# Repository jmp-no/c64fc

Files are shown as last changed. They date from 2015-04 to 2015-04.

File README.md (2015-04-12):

# c64fc
All software related to the C64FC (Commodore 64 Flash Cart)

Firmware:

Holds the source code to build and flash the firmware.

USBaspLoader 

- USB boot loader for the AVR.

c64firmware 

- firmware sourcecode.

Hardware:

Contains Hardware schematics of the C64FC card in brd/sch format.	
	
Software:

Qt64 

- QT GUI frontend to handle upload/download of c64 images.

SIDPlay 

- QT GUI frontend to handle SID playing.

cmd64 

- Command tools to upload/download/reset/set bootloader.	
libc64fc -libc64fc library. Needed for all above as dep.

C64 images/sids needs to be placed under ROMs/C64Music.

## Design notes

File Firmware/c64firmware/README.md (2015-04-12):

C64FC firmware:

Requires:

- avrdude
- avr-gcc (i.e arduino-1.x.0/hardware/tools/avr/bin/avr-gcc)

To build:

make

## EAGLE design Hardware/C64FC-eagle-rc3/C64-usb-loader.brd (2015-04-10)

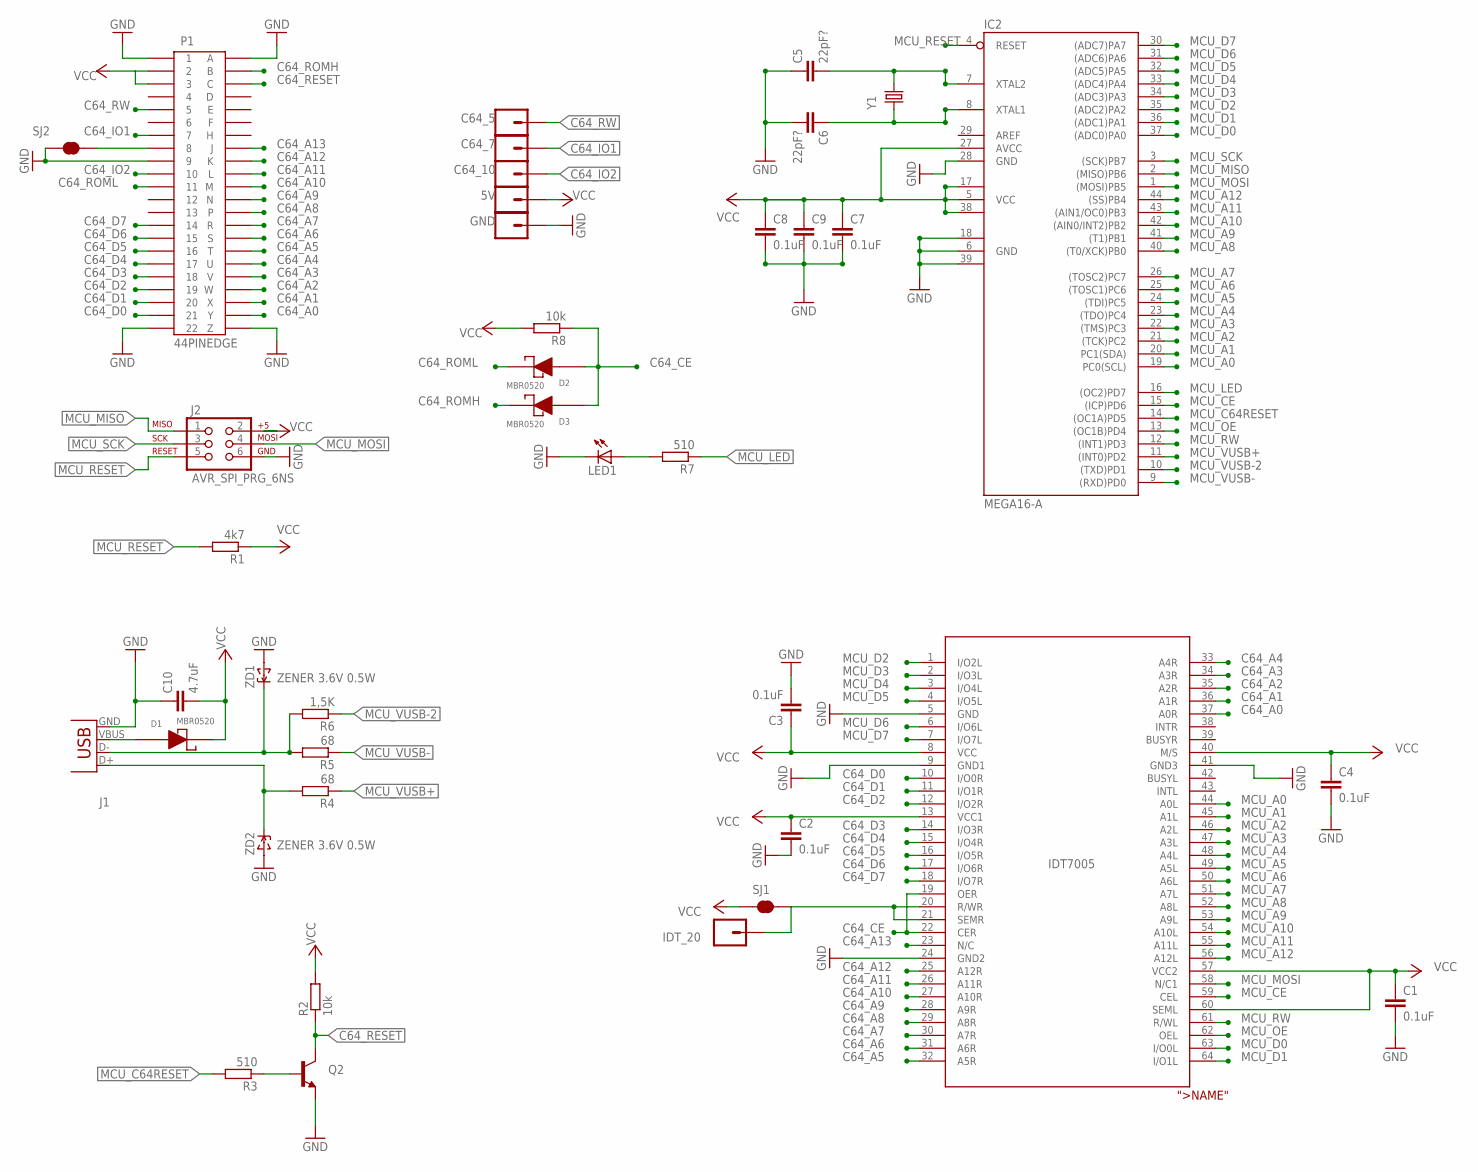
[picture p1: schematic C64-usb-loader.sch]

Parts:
5V: M01PTH; 1X01
C1, C2, C3, C4, C7, C8, C9: 0.1uF; C0805
C5, C6: 22pF?; C0805
C10: 4.7uF; C0805
C64_5, C64_7, C64_10: M01PTH; 1X01
D1, D2, D3: MBR0520; SOD-123; DIGIKEY MBR0520LCT-ND
GND: M01PTH; 1X01
IC1: IDT7005; TQFP64; DIGIKEY 800-1357-5-ND ??
IC2: MEGA16-A; TQFP44; DIGIKEY ATMEGA16A-AURCT-ND ??
IDT_20: M01PTH; 1X01
J1: USB-B; B; DIGIKEY ED2983-ND ??
J2: AVR_SPI_PRG_6NS; 2X3-NS
LED1: LED1206; LED-1206
P1: 44PINEDGE
Q2: TRANSISTOR_NPNSOT23-3; SOT23-3; DIGIKEY MMBT2222A-FDICT-ND
R1: 4k7; M0805
R2, R8: 10k; M0805
R3, R7: 510; M0805
R4, R5: 68; M0805
R6: 1,5K; M0805
SJ1, SJ2: JUMPER-PAD-2-NC_BY_TRACE; PAD-JUMPER-2-NC_BY_TRACE_YES_SILK
Y1: CRYSTALHC49US; HC49US
ZD1, ZD2: ZENER 3.6V 0.5W; SOD-123; DIGIKEY MMSZ5227B-FDICT-ND ??

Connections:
C64_A0: IC1.37 (A0R), P1.Y
C64_A1: IC1.36 (A1R), P1.X
C64_A2: IC1.35 (A2R), P1.W
C64_A3: IC1.34 (A3R), P1.V
C64_A4: IC1.33 (A4R), P1.U
C64_A5: IC1.32 (A5R), P1.T
C64_A6: IC1.31 (A6R), P1.S
C64_A7: IC1.30 (A7R), P1.R
C64_A8: IC1.29 (A8R), P1.P
C64_A9: IC1.28 (A9R), P1.N
C64_A10: IC1.27 (A10R), P1.M
C64_A11: IC1.26 (A11R), P1.L
C64_A12: IC1.25 (A12R), P1.K
C64_A13: IC1.23 (N/C), P1.J
C64_CE: D2.2 (AN), D3.2 (AN), IC1.19 (OER), IC1.22 (CER), R8.1
C64_D0: IC1.10 (I/O0R), P1.21
C64_D1: IC1.11 (I/O1R), P1.20
C64_D2: IC1.12 (I/O2R), P1.19
C64_D3: IC1.14 (I/O3R), P1.18
C64_D4: IC1.15 (I/O4R), P1.17
C64_D5: IC1.16 (I/O5R), P1.16
C64_D6: IC1.17 (I/O6R), P1.15
C64_D7: IC1.18 (I/O7R), P1.14
C64_GAME: P1.8, SJ2.2
C64_IO1: C64_7.1, P1.7
C64_IO2: C64_10.1, P1.10
C64_RESET: P1.C, Q2.3 (C), R2.1
C64_ROMH: D3.1 (CA), P1.B
C64_ROML: D2.1 (CA), P1.11
C64_RW: C64_5.1, P1.5
D+: J1.D+, R4.2, ZD2.C
D-: J1.D-, R5.2, R6.2, ZD1.C
GND: C1.2, C2.2, C3.2, C4.2, C5.1, C6.2, C7.2, C8.2, C9.2, C10.1, GND.1, IC1.5 (GND), IC1.9 (GND1), IC1.24 (GND2), IC1.41 (GND3), IC2.6 (GND), IC2.18 (GND1), IC2.28 (GND), IC2.39 (GND2), J1.GND, J2.6, LED1.C, P1.1, P1.9, P1.22, P1.A, P1.Z, Q2.2 (E), SJ2.1, ZD1.A, ZD2.A
MCU_A0: IC1.44 (A0L), IC2.19 (PC0(SCL))
MCU_A1: IC1.45 (A1L), IC2.20 (PC1(SDA))
MCU_A2: IC1.46 (A2L), IC2.21 ((TCK)PC2)
MCU_A3: IC1.47 (A3L), IC2.22 ((TMS)PC3)
MCU_A4: IC1.48 (A4L), IC2.23 ((TDO)PC4)
MCU_A5: IC1.49 (A5L), IC2.24 ((TDI)PC5)
MCU_A6: IC1.50 (A6L), IC2.25 ((TOSC1)PC6)
MCU_A7: IC1.51 (A7L), IC2.26 ((TOSC2)PC7)
MCU_A8: IC1.52 (A8L), IC2.40 ((T0/XCK)PB0)
MCU_A9: IC1.53 (A9L), IC2.41 ((T1)PB1)
MCU_A10: IC1.54 (A10L), IC2.42 ((AIN0/INT2)PB2)
MCU_A11: IC1.55 (A11L), IC2.43 ((AIN1/OC0)PB3)
MCU_A12: IC1.56 (A12L), IC2.44 ((SS)PB4)
MCU_C64RESET: IC2.14 ((OC1A)PD5), R3.2
MCU_CE: IC1.59 (CEL), IC2.15 ((ICP)PD6)
MCU_D0: IC1.63 (I/O0L), IC2.37 ((ADC0)PA0)
MCU_D1: IC1.64 (I/O1L), IC2.36 ((ADC1)PA1)
MCU_D2: IC1.1 (I/O2L), IC2.35 ((ADC2)PA2)
MCU_D3: IC1.2 (I/O3L), IC2.34 ((ADC3)PA3)
MCU_D4: IC1.3 (I/O4L), IC2.33 ((ADC4)PA4)
MCU_D5: IC1.4 (I/O5L), IC2.32 ((ADC5)PA5)
MCU_D6: IC1.6 (I/O6L), IC2.31 ((ADC6)PA6)
MCU_D7: IC1.7 (I/O7L), IC2.30 ((ADC7)PA7)
MCU_LED: IC2.16 ((OC2)PD7), R7.1
MCU_MISO: IC2.2 ((MISO)PB6), J2.1
MCU_MOSI: IC1.58 (N/C1), IC2.1 ((MOSI)PB5), J2.4
MCU_OE: IC1.62 (OEL), IC2.13 ((OC1B)PD4)
MCU_RESET: IC2.4 (RESET), J2.5, R1.2
MCU_RW: IC1.61 (R/WL), IC2.12 ((INT1)PD3)
MCU_SCK: IC2.3 ((SCK)PB7), J2.3
MCU_VUSB+: IC2.11 ((INT0)PD2), R4.1
MCU_VUSB-: IC2.9 ((RXD)PD0), R5.1
MCU_VUSB-2: IC2.10 ((TXD)PD1), R6.1
unnamed: Q2.1 (B), R3.1
unnamed: C5.2, IC2.7 (XTAL2), Y1.2
unnamed: IC1.20 (R/WR), IC1.21 (SEMR), IDT_20.1, SJ1.2
unnamed: C6.1, IC2.8 (XTAL1), Y1.1
unnamed: LED1.A, R7.2
VBUS: D1.2 (AN), J1.VBUS
VCC: 5V.1, C1.1, C2.1, C3.1, C4.1, C7.1, C8.1, C9.1, C10.2, D1.1 (CA), IC1.8 (VCC), IC1.13 (VCC1), IC1.40 (M/S), IC1.57 (VCC2), IC1.60 (SEML), IC2.5 (VCC), IC2.17 (VCC1), IC2.27 (AVCC), IC2.38 (VCC2), J2.2, P1.2, P1.3, R1.1, R2.2, R8.2, SJ1.1

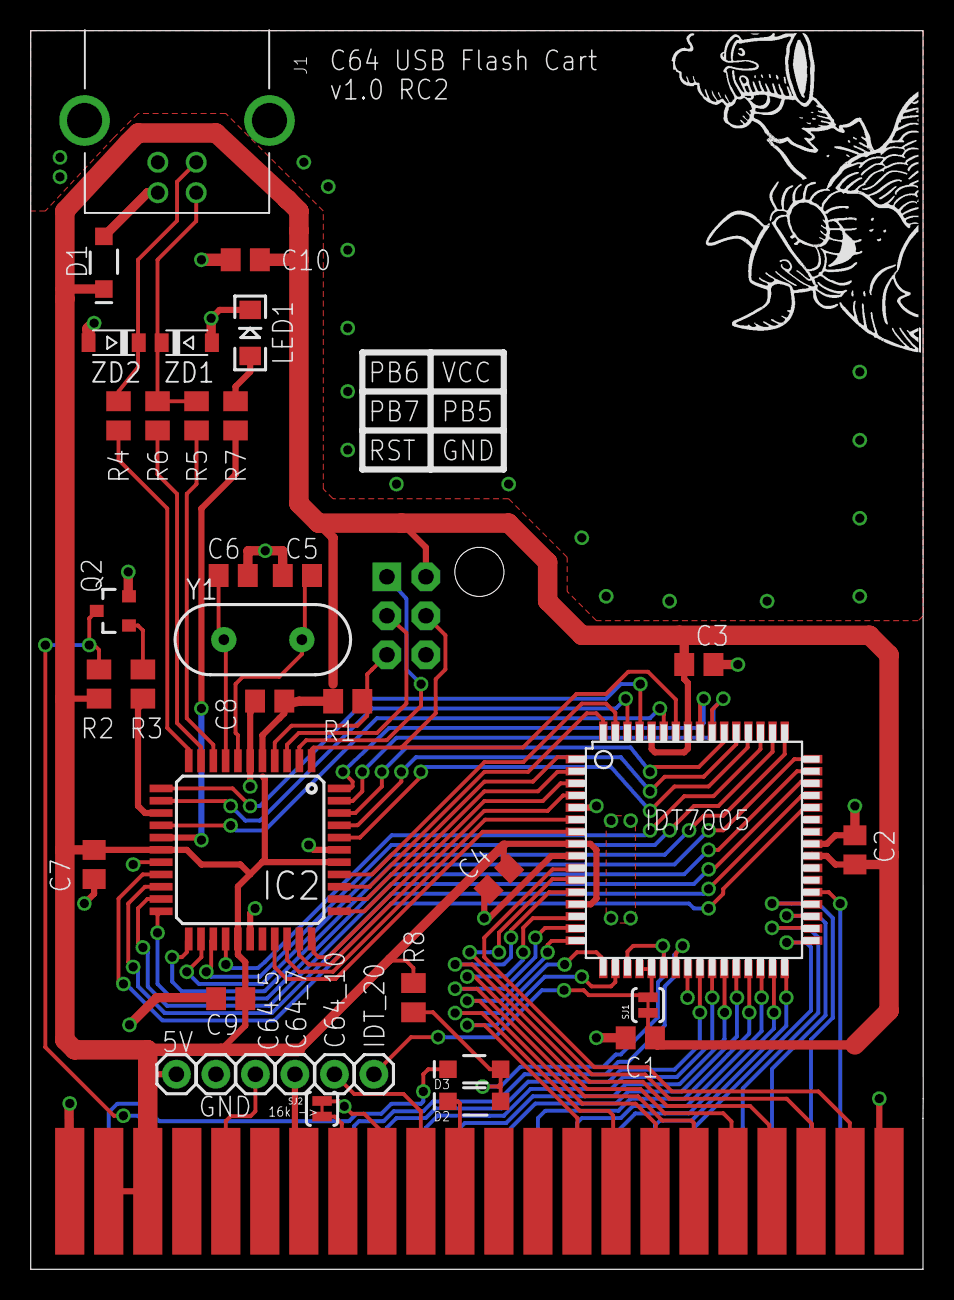
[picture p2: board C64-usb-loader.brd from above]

Board: 2 copper layers, 58.1 x 80.6 mm, 40 parts (0 on the bottom side), 73 nets.

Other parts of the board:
U$1: HAREK_20X16MM

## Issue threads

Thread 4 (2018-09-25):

the usbdrv used

bwack, 2018-09-25:
Hei. Lenge siden ! Alt over lenge siden.
Håper det er greit å spørre her ? Jeg har sett litt på firmware.

Jeg har "gått i stå" med videopac sdkort leser koden. Problemet er at menuprogrammet må ligge i rom når programmet overføres til ram via sd-cort -> videopac -> ram (fordi videopac styrer addressebussen selv, og for å slippe å bruke bustranscievers). Nå har jeg innsett at jeg trenger endel gluelogic + en rom brikke. Alikevel har jeg lyst å se om det går. Det er vanskelig å utvikle ved å brenne en rom hver gang, så kom jeg til å tenke på c64fc og dual port ram. Har veldig lyst å droppe hele designet og gå for arduino+ram+transcievers. Fordelen er jo også at man kan ha menuprogrammet på sdkort.. Kanskje starte med et kort som også har dualport ram slik at det blir lettere å utvikle (compile -> usb -> ram)..

Er det vanskelig å bruke usbdrv.h ? Jeg ser på koden og ser egentlig ganske greit ut :) Iallefal på mcu-siden. Ser ut som man trenger å definere noen funksjoner og en hid descriptor.

bwack, 2018-09-26:
Hadde det vært ok om jeg bruker ditt design for å lage et "break-out" kort med dpram, atmega og arduino ? Vi snakket en gang om å lage en standard for mange forskjellige cartridges. Akkurat nå tenker jeg på å bare lage en usb->rom utviklingskort :)

skurk, 2018-09-27:
Heisann, beklager sent svar.

V-USB er lett å bruke ja. Jeg betalte vel 10 euro for å få en unik ID. Du bruker hva du vil i utviklingsprosessen/testing, men for et "ferdig produkt" så kan det vel lønne seg å ha noe ryddig på plass.

Ikke noe problem å basere designet ditt på det jeg har heller. Er jo så og si klart, det du i all hovedsak trenger er en annen connector på enden, så er det tut og kjør. Ingenting C64-spesifikt med cartrigden annet enn connectoren...

bwack, 2018-10-01:
Takk! Har tegnet ett kort i KiCad basert på ditt kort. PCB designet er smellt sammen med autorouter bare for å ha noe å utvikle. Har bestilt komponenter og pcb. Håper på ha det klart i slutten av uka, begynnelsen av neste. :)

skurk, 2018-10-02:
Tøft! :-) Hold meg oppdatert med framgangen :)

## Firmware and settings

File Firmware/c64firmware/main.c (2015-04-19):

#include <avr/io.h>
#include <avr/interrupt.h>
#include <avr/pgmspace.h>
#include <avr/wdt.h>
#include <util/delay.h>

#include "usbdrv.h"

#include "c64.h"
#include "dpram.h"
#include "bootloader.h"
#include <string.h>    // Used for memcpy

#define C64FC_16K		0x16
#define C64FC_8K		0x08
#define C64FC_SETMODE   0x04

#define C64FC_GETSIZE   0x20

#define C64FC_RESET		0xf0
#define C64FC_WRITEDATA	0xcc
#define C64FC_READDATA	0xcd
#define C64FC_SETADDR	0x64

#define C64FC_BOOTLOADER 0xFE
#define C64FC_APIVERSION 0xF1


/* API Version
 * This is used to check that the cart and pc software is "talking the same language"
 * Increment this every time there is a change in the usb communication statck
*/
#define API_VERSION_HIGH 0x00;
#define API_VERSION_LOW  0x01;

#define LED_ON	PORTD |=  (1 << 7)
#define LED_OFF PORTD &= ~(1 << 7)
/*#define LED_ON	PORTD |= 0b10000000
#define LED_OFF PORTD &= 0b01111111*/

typedef struct __attribute__((packed)){
   uint16_t address;
   char len;
   char data[128];  
} dataBlock;

uint16_t address = 0;

uint8_t dataINFunction  = 0;
uint8_t dataOUTFunction = 0;
/* ------------------------------------------------------------------------- */
/* ----------------------------- USB interface ----------------------------- */
/* ------------------------------------------------------------------------- */

PROGMEM const char usbHidReportDescriptor[22] = {    /* USB report descriptor */
    0x06, 0x00, 0xff,              // USAGE_PAGE (Generic Desktop)
    0x09, 0x01,                    // USAGE (Vendor Usage 1)
    0xa1, 0x01,                    // COLLECTION (Application)
    0x15, 0x00,                    //   LOGICAL_MINIMUM (0)
    0x26, 0xff, 0x00,              //   LOGICAL_MAXIMUM (255)
    0x75, 0x08,                    //   REPORT_SIZE (8) 0x08
    0x95, 0x80,                    //   REPORT_COUNT (128)
    0x09, 0x00,                    //   USAGE (Undefined)
    0xb2, 0x02, 0x01,              //   FEATURE (Data,Var,Abs,Buf)
    0xc0                           // END_COLLECTION
};
/* Since we define only one feature report, we don't use report-IDs (which
 * would be the first byte of the report). The entire report consists of 128
 * opaque data bytes.
 */

/* The following va1iables store the status of the current data transfer */
static uchar    bytesRemaining;
//static uint8_t enter_bootloader = 0;

/* ------------------------------------------------------------------------- */

/* usbFunctionRead() is called when the host requests a chunk of data from
 * the device. For more information see the documentation in usbdrv/usbdrv.h.
 */
uchar   usbFunctionRead(uchar *data, uchar len)
{
    if(len > bytesRemaining)
        len = bytesRemaining;
    bytesRemaining -= len;

    return len;
}

/* usbFunctionWrite() is called when the host sends a chunk of data to the
 * device. For more information see the documentation in usbdrv/usbdrv.h.
 */


/* Jeg må bare innse at denne ikke kjøres for hver "packet", men deles opp utenfor min kontroll. */

uchar   usbFunctionWrite(uchar *data, uchar len)
{
	uint8_t i=0;
	LED_ON;

	if(bytesRemaining == 0)
		return 1;               // end of transfer 

	if(len > bytesRemaining)
		len = bytesRemaining;

	switch( dataINFunction ) {
		case 1:
			for( i = 0; i<len; i++ )
				DPRAM_write( address+i, (unsigned char) data[i] );
			address += len;
			break;
		case 2:
			address = ((unsigned char)data[0] << 8)|(unsigned char)data[1];
			break;
		case 3: 
		    /* MODE CHANGE */
			if      (data[0] == 0x00) C64_NOCART();
			else if (data[0] == 0x01) C64_8K();
			else if (data[0] == 0x02) C64_16K();
			else if (data[0] == 0x03) C64_ULTIMAX();

		    break;
		default:
			break;
	}

	bytesRemaining -= len;
	LED_OFF;
	return bytesRemaining == 0; // return 1 if this was the last chunk 
}

/* ------------------------------------------------------------------------- */

usbMsgLen_t usbFunctionSetup(uchar data[8])
{
	usbRequest_t    *rq = (void *)data;

	uint8_t retval = USB_NO_MSG;

	LED_ON;

	if((rq->bmRequestType & USBRQ_TYPE_MASK) == USBRQ_TYPE_CLASS) {
		if(rq->bRequest == USBRQ_HID_SET_REPORT){
			uint8_t command = rq->wValue.bytes[0];
			switch( command ) {
				case C64FC_8K:
					/* 0x08 8k mode
					 * Makes the C64FC enter 8k mode 
					 * Then reboots the C64 to load data from C64FC
					 */
					C64_EXROM(0);
					C64_GAME(1);
					C64_Reset();
					LED_OFF;
					retval = 1;
					bytesRemaining = 0;
					break;
				case C64FC_16K:
					/* 0x16 16k mode
					 * Makes the C64FC enter 16k mode 
					 * Then reboots the C64 to load data from C64FC
					 */
					C64_EXROM(0);
					C64_GAME(0);
					C64_Reset();
					LED_OFF;
					retval = 1;
					bytesRemaining = 0;
					break;
				case C64FC_SETMODE:
					/* Changes mode on the cart
					 * Same function for all modes
					 * uses parameter from PC, values: 
					 * 0: diabled , 1: 8k,    2: 16k , 3: ultimax
					 */
					bytesRemaining = rq->wLength.bytes[0];
					dataINFunction = 3;
					break;
				case C64FC_WRITEDATA:
					/* 0xCC Send Data
					 * Data sent from pc to the C64FC
					 * Uses usbFunctionWrite to save recieved data to RAM
					 * Saves data to address set with C64FC_SETADDR
					 */
					bytesRemaining = rq->wLength.bytes[0];
					dataINFunction = 1;
					break;
				case C64FC_SETADDR:
					/* 0x64 Set Address
					 * Sets the address for the next read/write operation
					 * Uses usbFunctionWrite to get the address
					 */
					//bytesRemaining = rq->wLength.bytes[0];  // This did'nt work.. :( dont know if its because of S64FC or client software...)
					dataINFunction = 2;
					bytesRemaining = 2;

					break;
				case C64FC_RESET:
					/* 0xF0 Reset C64
					 * Resets the C64 
					 */
					//address = 0;
					C64_Reset();
					LED_OFF;
					retval = 1;
					bytesRemaining = 0;
					break;
				case C64FC_BOOTLOADER:
					/* 0xFE Enter Bootloader
					 * Puts the C64FC in bootloader mode.
					 * C64FC will be stuck in UsbASPloader until MCUCSR != 0 or avrdude sends a exit command.
					 * 
					 */
					 wdt_disable();
					MCUCSR = 0;
					bootloader_jump();		// This needs to be moved... bootloader_jump is creating a "Broken pipe on the host.."
										// Create a var and check for it in main:for(;;)  then execute bootloader_jump() before the next usb_poll.
					//enter_bootloader = 1;
					
					break;
			}
		} else if(rq->bRequest == USBRQ_HID_GET_REPORT){
			uint8_t command = rq->wValue.bytes[0];
			//uint8_t index0 = rq->wIndex.bytes[0];
			//uint8_t index1 = rq->wIndex.bytes[1];
			static uchar smallReturnBuffer[10];
			static uchar largeReturnBuffer[128];

			switch ( command ) {			
				case 0x01: ;
					/* 0x01 Return fubar to PC
					 * only for testing.. :)
					 *  --runar
					 */
					LED_OFF;
					retval = 6;
					static uchar pointer[5] = "fiske";
					usbMsgPtr = pointer;
					DPRAM_write(0x00, (uint8_t)'f');
					DPRAM_write(0x01, (uint8_t)'u');
					DPRAM_write(0x02, (uint8_t)'b');
					DPRAM_write(0x03, (uint8_t)'a');
					DPRAM_write(0x04, (uint8_t)'r');
					pointer[0] = DPRAM_read(0x00);
					pointer[1] = DPRAM_read(0x01);
					pointer[2] = DPRAM_read(0x02);
					pointer[3] = DPRAM_read(0x03);
					pointer[4] = DPRAM_read(0x04);
					pointer[4] = rq->wLength.bytes[0];
					LED_OFF;
					break;
				case C64FC_GETSIZE:	;
					/* 0x20 Get size of DPRAM
					 * Calculates the size of your DPRAM chip.
					 * supports 8k and 16k.
					 * Writes to 0x0 and compares with value at 0x2000.
					 * Se DPRAM_size in dpram.c for more info
					 */
					if (DPRAM_size() == 0x2000)
						smallReturnBuffer[0] =  8;
					else
						smallReturnBuffer[0] = 16;
					retval=10;				// Retval on GET request is number of bytes returned
					usbMsgPtr = smallReturnBuffer;
					LED_OFF;
					break;
				case C64FC_READDATA: ;
					/* 0xCD Read data from device
					 * Reads data from address set by C64FC_SETADDR
					 * 
					 */
					uint8_t i;
					for( i = 0; i<rq->wLength.bytes[0]; i++ ) {
						largeReturnBuffer[i] = DPRAM_read( address+i );
					}
					address  += rq->wLength.bytes[0];	// Address is incremented for next read...
					retval    = rq->wLength.bytes[0];	// Retval on GET request is number of bytes returned
					usbMsgPtr = largeReturnBuffer;
					LED_OFF;
					break;
				case C64FC_APIVERSION: ;
					/* 0xF1 API Version
					 * This is used to check that the cart and pc software is "talking the same language"
					 * API_VERSION_HIGH/LOW is incremented every time there is a change in the usb protocoll stack.
					 */
					smallReturnBuffer[0] = API_VERSION_HIGH;
					smallReturnBuffer[1] = API_VERSION_LOW;
					retval=2;				// Retval on GET request is number of bytes returned
					usbMsgPtr = smallReturnBuffer;
					LED_OFF;
					break;
			}

		}
	}
	return( retval );
}

/* ------------------------------------------------------------------------- */

int main(void) {
uchar   i;

	C64_init();
	DPRAM_init();
	DPRAM_clear(0x0,0x4000);

	wdt_enable(WDTO_1S);
	usbInit();
	usbDeviceDisconnect();

	DDRD |= (1 << 7);    // LED init
//	DDRD |= (0b10000000);    // LED init
	LED_ON;
	i = 0;
	while(--i){
		wdt_reset();
		_delay_ms(1);
	}
	LED_OFF;

	usbDeviceConnect();
	sei();

	DPRAM_init();

// 8k mode
	C64_EXROM(1);
	C64_GAME(1);
	C64_Reset();

	for(;;) {                /* main event loop */
		wdt_reset();
		usbPoll();

/*		if (enter_bootloader > 0)
			enter_bootloader++;
			if (enter_bootloader <= 1000) {
				wdt_disable();
				MCUCSR = 0;
				bootloader_jump();		// This needs to be moved... bootloader_jump is creating a "Broken pipe on the host.."
										// Create a var and check for it in main:for(;;)  then execute bootloader_jump() before the next usb_poll.
			}*/
	}
	return 0;
}

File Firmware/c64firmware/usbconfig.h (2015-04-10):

/* Name: usbconfig.h
 * Project: AVR USB driver
 * Author: Christian Starkjohann
 * Creation Date: 2005-04-01
 * Tabsize: 4
 * Copyright: (c) 2005 by OBJECTIVE DEVELOPMENT Software GmbH
 * License: GNU GPL v2 (see License.txt) or proprietary (CommercialLicense.txt)
 * This Revision: $Id: usbconfig.h 43 2005-04-10 21:04:36Z cs $
 */

#ifndef __usbconfig_h_included__
#define __usbconfig_h_included__

/*
General Description:
This file contains parts of the USB driver which can be configured and can or
must be adapted to your hardware.

Please note that the usbdrv contains a usbconfig-prototype.h file now. We
recommend that you use that file as a template because it will always list
the newest features and options.
*/

/* ---------------------------- Hardware Config ---------------------------- */

#define USB_CFG_CLOCK_KHZ       (F_CPU/1000)

#define USB_CFG_IOPORTNAME      D
/* This is the port where the USB bus is connected. When you configure it to
 * "B", the registers PORTB, PINB and DDRB will be used.
 */
#define USB_CFG_DMINUS_BIT      0
/* This is the bit number in USB_CFG_IOPORT where the USB D- line is connected.
 * This may be any bit in the port.
 */
#define USB_CFG_DPLUS_BIT       2
/* This is the bit number in USB_CFG_IOPORT where the USB D+ line is connected.
 * This may be any bit in the port. Please note that D+ must also be connected
 * to interrupt pin INT0!
 */
/* #define USB_CFG_CLOCK_KHZ       (F_CPU/1000) */
/* Clock rate of the AVR in MHz. Legal values are 12000, 16000 or 16500.
 * The 16.5 MHz version of the code requires no crystal, it tolerates +/- 1%
 * deviation from the nominal frequency. All other rates require a precision
 * of 2000 ppm and thus a crystal!
 * Default if not specified: 12 MHz
 */

/* ----------------------- Optional Hardware Config ------------------------ */

#define USB_CFG_PULLUP_IOPORTNAME   D 
/* If you connect the 1.5k pullup resistor from D- to a port pin instead of
 * V+, you can connect and disconnect the device from firmware by calling
 * the macros usbDeviceConnect() and usbDeviceDisconnect() (see usbdrv.h).
 * This constant defines the port on which the pullup resistor is connected.
 */
 #define USB_CFG_PULLUP_BIT          1
/* This constant defines the bit number in USB_CFG_PULLUP_IOPORT (defined
 * above) where the 1.5k pullup resistor is connected. See description
 * above for details.
 */

/* --------------------------- Functional Range ---------------------------- */

#define USB_CFG_HAVE_INTRIN_ENDPOINT    1
/* Define this to 1 if you want to compile a version with two endpoints: The
 * default control endpoint 0 and an interrupt-in endpoint 1.
 */
#define USB_CFG_HAVE_INTRIN_ENDPOINT3   0
/* Define this to 1 if you want to compile a version with three endpoints: The
 * default control endpoint 0, an interrupt-in endpoint 1 and an interrupt-in
 * endpoint 3. You must also enable endpoint 1 above.
 */
#define USB_CFG_IMPLEMENT_HALT          0
/* Define this to 1 if you also want to implement the ENDPOINT_HALT feature
 * for endpoint 1 (interrupt endpoint). Although you may not need this feature,
 * it is required by the standard. We have made it a config option because it
 * bloats the code considerably.
 */
#define USB_CFG_INTR_POLL_INTERVAL      10
/* If you compile a version with endpoint 1 (interrupt-in), this is the poll
 * interval. The value is in milliseconds and must not be less than 10 ms for
 * low speed devices.
 */
#define USB_CFG_IS_SELF_POWERED         1
/* Define this to 1 if the device has its own power supply. Set it to 0 if the
 * device is powered from the USB bus.
 */
#define USB_CFG_MAX_BUS_POWER           20
/* Set this variable to the maximum USB bus power consumption of your device.
 * The value is in milliamperes. [It will be divided by two since USB
 * communicates power requirements in units of 2 mA.]
 */
#define USB_CFG_IMPLEMENT_FN_WRITE      1
/* Set this to 1 if you want usbFunctionWrite() to be called for control-out
 * transfers. Set it to 0 if you don't need it and want to save a couple of
 * bytes.
 */
#define USB_CFG_IMPLEMENT_FN_READ       1
/* Set this to 1 if you need to send control replies which are generated
 * "on the fly" when usbFunctionRead() is called. If you only want to send
 * data from a static buffer, set it to 0 and return the data from
 * usbFunctionSetup(). This saves a couple of bytes.
 */
#define USB_CFG_IMPLEMENT_FN_WRITEOUT   0
/* Define this to 1 if you want to use interrupt-out (or bulk out) endpoint 1.
 * You must implement the function usbFunctionWriteOut() which receives all
 * interrupt/bulk data sent to endpoint 1.
 */
#define USB_CFG_HAVE_FLOWCONTROL        0
/* Define this to 1 if you want flowcontrol over USB data. See the definition
 * of the macros usbDisableAllRequests() and usbEnableAllRequests() in
 * usbdrv.h.
 */
/* #define USB_RX_USER_HOOK(data, len)     if(usbRxToken == (uchar)USBPID_SETUP) blinkLED(); */
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

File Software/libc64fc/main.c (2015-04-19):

#include <stdio.h>
#include <string.h>
#include <unistd.h>
#include <math.h>
#include <usb.h>
#include "hiddata.h"
#include "../usbconfig.h"
#include "c64fc.h"


usbDevice_t *dev = NULL;
unsigned char buffer[129];

int OpenDevice() {
	unsigned char vendor_id[2] = { USB_CFG_VENDOR_ID };
	unsigned char product_id[2] = { USB_CFG_DEVICE_ID };
	char vendorName[] = { USB_CFG_VENDOR_NAME, 0 };
	char productName[] = { USB_CFG_DEVICE_NAME, 0 };
	int vid = vendor_id[0] + 256*vendor_id[1];
	int pid = product_id[0] + 256*product_id[1];
	int status;
	status = usbhidOpenDevice( &dev, vid, "jmp.no", pid, "C64FC-16", 0 );
	if (status == 0) return status;
	status = usbhidOpenDevice( &dev, vid, "jmp.no", pid, "C64FC-08", 0 );
	if (status == 0) return status;
	status = usbhidOpenDevice( &dev, vid, "jmp.no", pid, "C64FC", 0 );
	return( status );
}

void CloseDevice() {
	if( dev ) usbhidCloseDevice( dev );
	dev = NULL;
}

int Reset() {
	memset( buffer, 0, sizeof( buffer ));
	buffer[0] = C64FC_RESET;
	return( usbhidSetReport( dev, (char *) buffer, 1 ));
}

void SetAddress( unsigned short addr ) {
	int err=0;
	buffer[0] = C64FC_SETADDR;
	buffer[1] = (addr>>8)&0xff;
	buffer[2] = (addr&0xff);
	err = usbhidSetReport( dev, (char *) buffer, 129);
//	printf( "SetAddr=$%04x sent, response=%d\n", addr, err );
}


void Set8KMode() {
	int err = 0;
	buffer[0] = C64FC_8K;
	err = usbhidSetReport( dev, (char *) buffer, 1);
	printf( "SetCartMode=%d, res=%d", 8, err );
	Reset();
}

void Set16KMode() {
	int err = 0;
	buffer[0] = C64FC_16K;
	err = usbhidSetReport( dev, (char *) buffer, 1);
	printf( "SetCartMode=%d, res=%d", 16, err );
	Reset();
}

void SetMode(uint8_t mode) {
	/* Sets the GAME / EXROM pins on the C64
	 * Change is done without rebooting C64
	 * Parameter is the enum C64_MODE
	 */
	int err = 0;
	buffer[0] = C64FC_SETMODE;
	buffer[1] = mode;
	err = usbhidSetReport( dev, (char *) buffer, 1);
	printf( "SetCartMode=%d, res=%d", mode, err );
	Reset();
}
// Forslag til rewrite av WriteData...    
int WriteData( unsigned short address, unsigned char *data, int size ) {
	int err = 0;
	int chunk_no=0;
	int offset=0;

	if( !dev ) OpenDevice();
	SetAddress( address );

	while( size > 0 ) {

		int chunk_size = (size>=128)?128:size;
		memcpy( buffer+1, data+offset, chunk_size );
		buffer[0] = C64FC_DATA;
		printf( "Sending chunk %d (%d bytes) to $%04x..\n", chunk_no, chunk_size, address );
		//err = usbhidSetReport( dev, (char *) buffer, 129);
		err = usbhidSetReport( dev, (char *) buffer, chunk_size+1);  // <-- len is set to chunk_size+1.. wee need to remember the first reportid char... 
//		printf( "Sent\n" );
		if( err != 0 ) return( err );
		size -= chunk_size;
		address += chunk_size;
		offset += chunk_size;
		chunk_no++;
	}
	return( 0 );

}

int getFubar(char *buff) {
	char buffer[6];
	int len = 0x80;
	int err = 0;
    if((err = usbhidGetReport(dev, 0x01, (char *)buffer, &len)) != 0){
        //fprintf(stderr, "error reading data: %s\n", usbErrorMessage(err));
        printf("usb error of some kind");
        return 0;
    }else{
            memcpy(buff, buffer+1,len-1);
    }
    //printf("d: %s", buffer);
    return len-1;
}

int getData(uint16_t address, char *data, uint8_t size) {
	/*

		NB! size needs to be 128 or less.... usb cant return any lager bulks by default....

	*/
	char buffer[129];		// Max result size - 1
	int len = size+1;
	int err = 0;
	SetAddress( address );

    if((err = usbhidGetReport(dev, C64FC_READDATA, (char *)buffer, &len)) != 0){
        //fprintf(stderr, "error reading data: %s\n", usbErrorMessage(err));
        printf("usb error of some kind");
        return 0;
    }else{
            memcpy(data, buffer+1,len-1);
    }
    //printf("d: %s", buffer);
    return len-1;
}

unsigned int GetRamSize() {
	char buffer[11];
	int len = 10;
	int err = 0;
    if((err = usbhidGetReport(dev, C64FC_GETSIZE, (char *)buffer, &len)) != 0){
        //fprintf(stderr, "error reading data: %s\n", usbErrorMessage(err));
        printf("usb error of some kind");
        return 0x0;
    }
    //printf("d: %x", buffer[1]);
    return (unsigned int)buffer[1];

}

unsigned int GetApiVersion() {
	char buffer[11];
	int len = 2;
	int err = 0;
    if((err = usbhidGetReport(dev, C64FC_APIVERSION, (char *)buffer, &len)) != 0){
        //fprintf(stderr, "error reading data: %s\n", usbErrorMessage(err));
        printf("usb error of some kind");
        return 0x0;
    }
    //printf("d: %x", buffer[1]);
    return (uint16_t)(buffer[1] | (buffer[2] << 8));

}


void EnterBootloader() {
	int err = 0;
	buffer[0] = C64FC_BOOTLOADER;
	err = usbhidSetReport( dev, (char *) buffer, 1);
	printf( "EnterBootloader=%d, res=%d", 16, err );
}

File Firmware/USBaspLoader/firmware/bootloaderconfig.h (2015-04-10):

/* Name: bootloaderconfig.h
 * Project: USBaspLoader
 * Author: Christian Starkjohann
 * Author: Stephan Baerwolf
 * Creation Date: 2007-12-08
 * Modification Date: 2013-03-31
 * Tabsize: 4
 * Copyright: (c) 2007 by OBJECTIVE DEVELOPMENT Software GmbH
 * License: GNU GPL v2 (see License.txt)
 */

#ifndef __bootloaderconfig_h_included__
#define __bootloaderconfig_h_included__
#include "../misc/iofixes.h"

/*
General Description:
This file (together with some settings in Makefile) configures the boot loader
according to the hardware.

This file contains (besides the hardware configuration normally found in
usbconfig.h) two functions or macros: bootLoaderInit() and
bootLoaderCondition(). Whether you implement them as macros or as static
inline functions is up to you, decide based on code size and convenience.

bootLoaderInit() is called as one of the first actions after reset. It should
be a minimum initialization of the hardware so that the boot loader condition
can be read. This will usually consist of activating a pull-up resistor for an
external jumper which selects boot loader mode.

bootLoaderCondition() is called immediately after initialization and in each
main loop iteration. If it returns TRUE, the boot loader will be active. If it
returns FALSE, the boot loader jumps to address 0 (the loaded application)
immediately.

For compatibility with Thomas Fischl's avrusbboot, we also support the macro
names BOOTLOADER_INIT and BOOTLOADER_CONDITION for this functionality. If
these macros are defined, the boot loader usees them.
*/

/* ---------------------------- Macro Magic ---------------------------- */
#define		PIN_CONCAT(a,b)			a ## b
#define		PIN_CONCAT3(a,b,c)		a ## b ## c

#define		PIN_PORT(a)			PIN_CONCAT(PORT, a)
#define		PIN_PIN(a)			PIN_CONCAT(PIN, a)
#define		PIN_DDR(a)			PIN_CONCAT(DDR, a)

#define		PIN(a, b)			PIN_CONCAT3(P, a, b)


/* ---------------------------- C64FC    Config ---------------------------- */
/* This section if cor custom config needed for the C64FC card */
#define USB_CFG_IOPORTNAME      D
#define USB_CFG_INTPORT_BIT     2     // Does also set DPLUS_BIT
#define USB_CFG_DMINUS_BIT      0

#define USB_CFG_PULLUP_IOPORTNAME   D
#define USB_CFG_PULLUP_BIT          1

#define JUMPER_PORT		          B
#define JUMPER_BIT              5





/* ---------------------------- Hardware Config ---------------------------- */

#ifndef USB_CFG_IOPORTNAME
  #define USB_CFG_IOPORTNAME      D
#endif
/* This is the port where the USB bus is connected. When you configure it to
 * "B", the registers PORTB, PINB and DDRB will be used.
 */
#ifndef USB_CFG_INTPORT_BIT
  #if (defined(__AVR_ATmega640__) || defined (__AVR_ATmega128__) || defined(__AVR_ATmega1280__) || defined(__AVR_ATmega1281__) || defined(__AVR_ATmega2560__) || defined(__AVR_ATmega2561__))
    #define USB_CFG_INTPORT_BIT 0
  #else
    #define USB_CFG_INTPORT_BIT 2
  #endif
#endif
/* Not all devices have their INT0 on PD2.
 * Since "INT0" and "USB_CFG_DPLUS_BIT" should get the same signals,
 * map them to be ideally the same:
 * So abstract "USB_CFG_DPLUS_BIT" to this one here.
 */
#ifndef USB_CFG_DMINUS_BIT
/* This is Revision 3 and later (where PD6 and PD7 were swapped */
  #define USB_CFG_DMINUS_BIT      7    /* Rev.2 and previous was 6 */
#endif
/* This is the bit number in USB_CFG_IOPORT where the USB D- line is connected.
 * This may be any bit in the port.
 */
#ifndef USB_CFG_DPLUS_BIT
  #define USB_CFG_DPLUS_BIT       USB_CFG_INTPORT_BIT
#endif
/* This is the bit number in USB_CFG_IOPORT where the USB D+ line is connected.
 * This may be any bit in the port. Please note that D+ must also be connected
 * to interrupt pin INT0!
 */
#ifndef JUMPER_PORT
  #define JUMPER_PORT		USB_CFG_IOPORTNAME
#endif
/* 
 * jumper is connected to this port
 */
#ifndef JUMPER_BIT
  /* This is Revision 3 and later (where PD6 and PD7 were swapped */
  #define JUMPER_BIT           6       /* Rev.2 and previous was 7 */
#endif
/* 
 * jumper is connected to this bit in port "JUMPER_PORT", active low
 */

#define USB_CFG_CLOCK_KHZ       (F_CPU/1000)
/* Clock rate of the AVR in MHz. Legal values are 12000, 16000 or 16500.
 * The 16.5 MHz version of the code requires no crystal, it tolerates +/- 1%
 * deviation from the nominal frequency. All other rates require a precision
 * of 2000 ppm and thus a crystal!
 * Default if not specified: 12 MHz
 */

/* ----------------------- Optional Hardware Config ------------------------ */
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

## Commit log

2015-04-10 Initial import of Eagle files
    [C64-usb-loader.brd, C64-usb-loader.sch]
2015-04-10 Removed C64FC_EEPROM_SIZE from usbconfig.h
    This configuration was used to calculate cart rom-size, but it not used
    any more…
2015-04-10 Renamed usb name to C64FC
    size is calculated dynamically by the client, so we don’t need any
    identifier for the size any more
2015-04-19 Set Mode
    Function to Set GAME and EXROM status on the C64. sets all 4 modes in
    the same function, and does not reboot the C64 when changing mode
    [main.c]

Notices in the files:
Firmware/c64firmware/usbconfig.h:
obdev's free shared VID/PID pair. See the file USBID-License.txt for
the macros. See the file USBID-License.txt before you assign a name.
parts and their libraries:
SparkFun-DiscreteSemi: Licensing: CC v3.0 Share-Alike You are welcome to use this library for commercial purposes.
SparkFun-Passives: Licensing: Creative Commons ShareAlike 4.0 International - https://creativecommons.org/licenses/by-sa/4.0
